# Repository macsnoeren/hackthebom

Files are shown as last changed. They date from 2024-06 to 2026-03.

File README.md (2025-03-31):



# Hack the Bom - Escape room challenge for cyber security

An escape room challenge type developed for the Avans University of Applied Sciences minor Cybersecurity: Resslient against cyber-crime.

Flash the latest version to your hardware: https://macsnoeren.github.io/hackthebom/

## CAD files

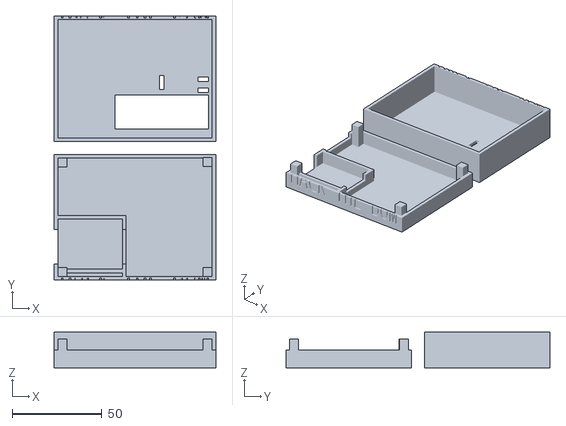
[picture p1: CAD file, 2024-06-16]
hardware/HackTheBox Casing.stl
90.0 x 147.0 x 20.0

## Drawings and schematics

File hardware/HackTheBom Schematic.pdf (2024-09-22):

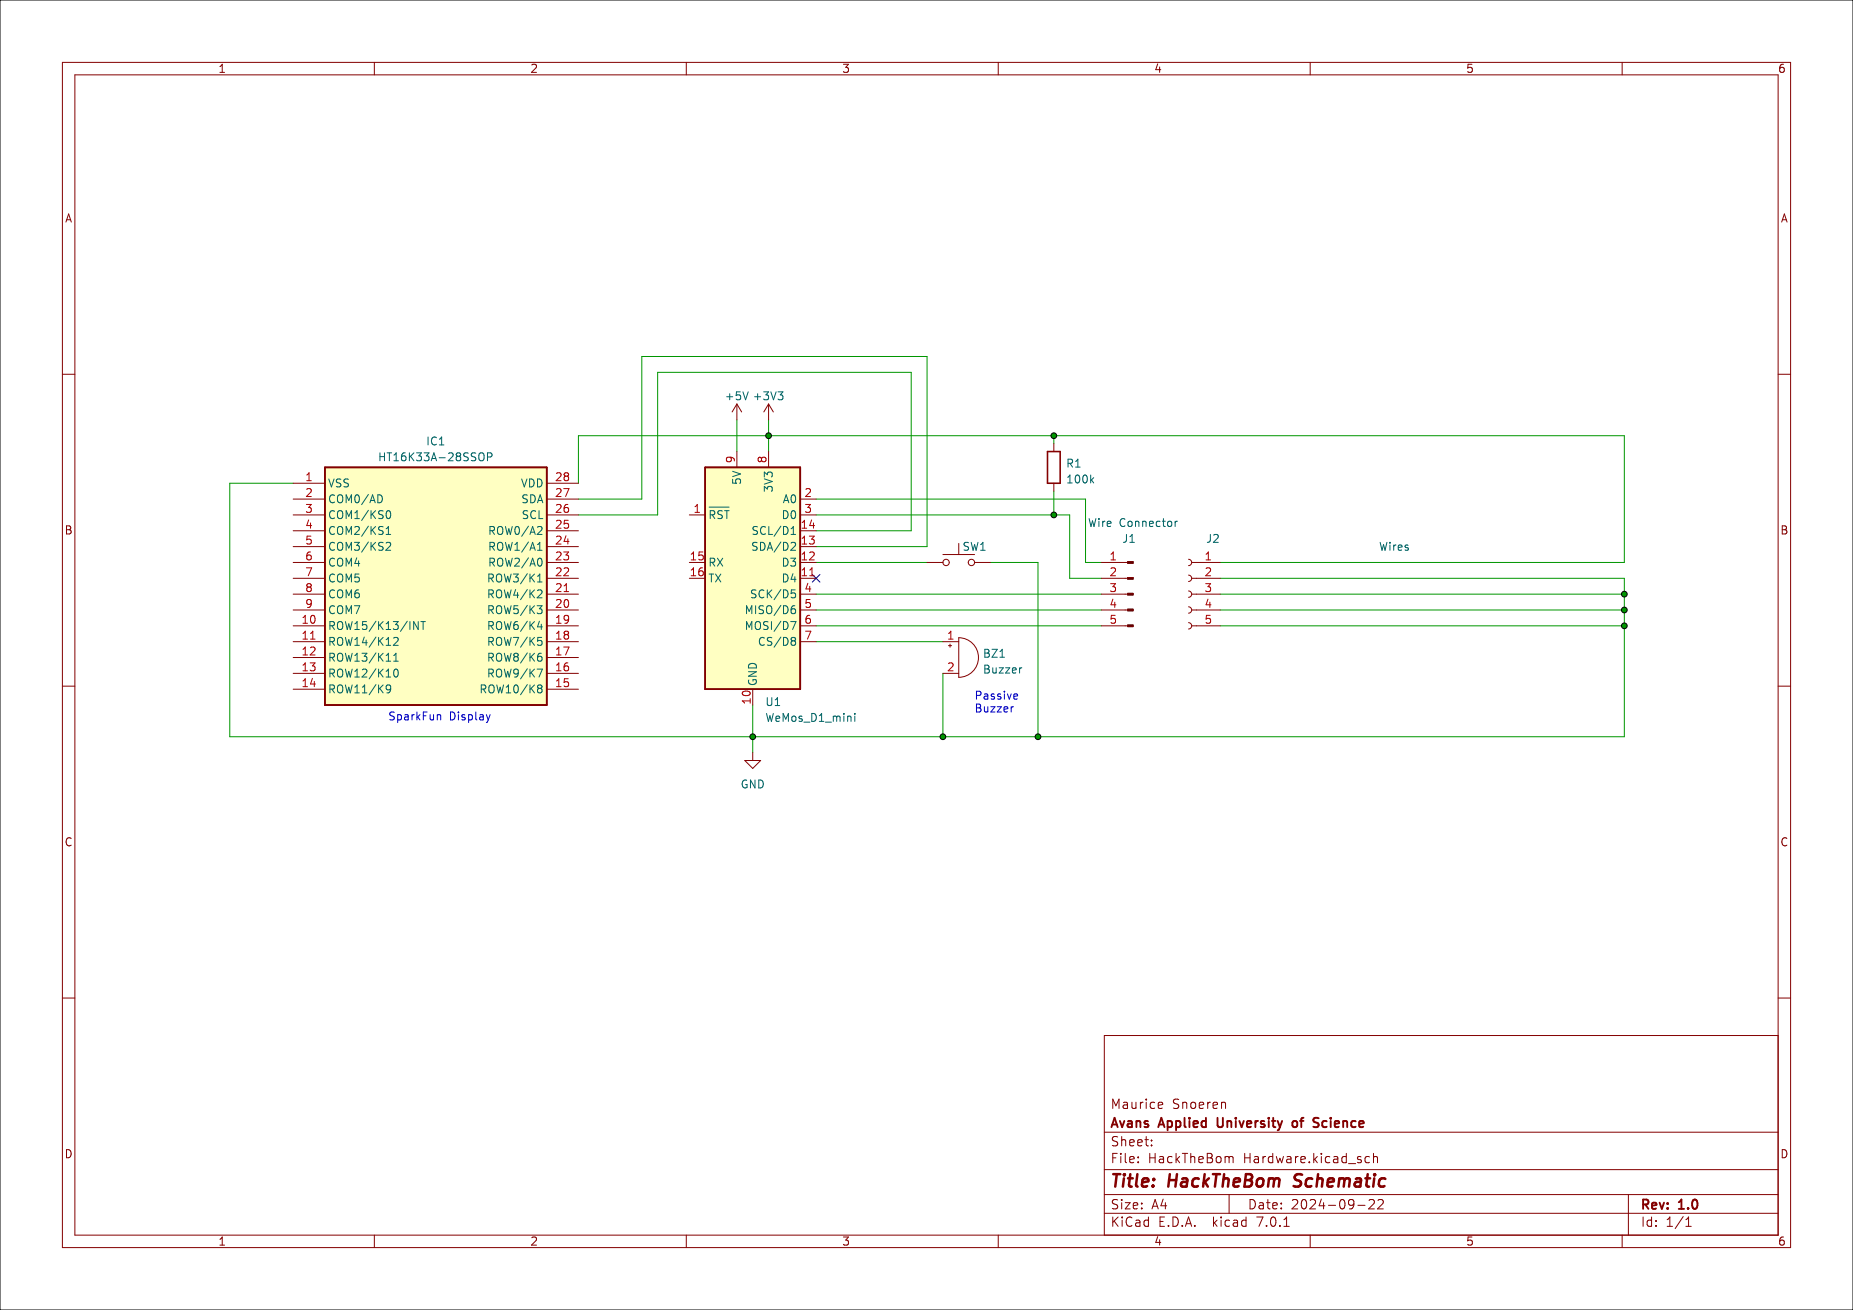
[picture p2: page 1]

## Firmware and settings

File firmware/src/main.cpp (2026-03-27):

/*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
 * @file       : main.cpp
 * @author     : Maurice Snoeren (MS)
 * @description: Main of the HackTheBom firmware application. HackTheBom is an
 *               escape room game that is used within Avans Hogeschool to teach
 *               students cyber security skills and knowledge. When the firmware
 *               starts, the teacher is able to select first the game that will
 *               be played. Enter the game is done using a long button press. 
 *               Then the time that the students get is selected and again with a
 *               long button press it is selected. To start the game the button
 *               is pressed again. The timer will start and the students need to
 *               solve the puzzle to defuse the (fake) bomb.
 *               The hardware:
 *               - Passive buzzer connected to D8 and GND.
 *               - 7-segment display connected to SCL (D1), SDA (D2), 5V and GND.
 *               - Button connected to D3.
 *               - 5 defuse wires connected to 1 (A0), 2 (D0), 3 (D5), 4 (D6), 5 (D7)
 *                 Wire connections: - A0 --- 3V3
 *                                   - D0 --- GND (external pull-up 100K to 3V3)
 *                                   - D5/D6/D7 --- GND (select internal pull-up)
 * @date       : 27-03-2026
 * @version    : 1.2
 * @updates    : 20-02-2024 (MS): Initial code.
 *               16-06-2024 (MS): Created the first release version.
 *               22-09-2024 (MS): Added Game 2 for the first year students including game selection.
 *               27-03-2026 (MS): Improved code and documentation.
 * @todo       : 
 */
#include <Arduino.h>
#include <math.h>
#include <ESP8266WiFi.h>
#include <ESP8266WebServer.h>
#include <EEPROM.h>
#include <driver.h>
#include <website.hpp>
#include <timer.hpp>
#include <buzzer.hpp>
#include <button.hpp>
#include <wires.hpp>

/// @brief Unieke SSID gebaseerd op de Chip ID.
String SSID = "HTB-" + String(system_get_chip_id());

/// @brief Wi-Fi wachtwoord (wordt geladen uit EEPROM of random gegenereerd).
String PASSWORD = "";

int channel = random(1, 13);
uint8_t GAME_SELECTION = 0;

// Forward declaration of the different routes for the webpages.
void handleRoot();
void handleAdmin();
void handleCode();
void handleNotFound();
String webDefusingCode = "";
uint8_t webDefusingCodeTrials = 0;

// Instantieer hardware drivers.
Timer timer;
Buzzer buzzer;
Button button;
Wires wires(&buzzer);
IDriver *drivers[] = { (IDriver*) &timer,
                       (IDriver*) &buzzer,
                       (IDriver*) &button,
                       (IDriver*) &wires,
                     };

ESP8266WebServer server(80);

/**
 * @enum MAIN_STATES
 * @brief De staten van de hoofd-state machine van het spel.
 */
enum MAIN_STATES {
  SELECT_GAME, ///< De leraar kiest het speltype.
  SELECT_TIME, ///< De leraar stelt de beschikbare tijd in.
  READY,       ///< Systeem is klaar voor de start (wacht op knopdruk).
  GAME_1,      ///< Game 1 (Draden) is actief.
  GAME_2,      ///< Game 2 (Web hacking) is actief.
  WIN,         ///< De bom is succesvol ontmanteld.
  LOSE,        ///< De bom is afgegaan.
  END,         ///< Einde van het spel, wacht op herstart.
};

// FSM state variable that indicate in which state we are in.
MAIN_STATES stateMain = SELECT_GAME;

// Total time that students get as default value in minutes (50 minutes).
uint8_t totalTimeDefault = 50;

/**
 * @brief Arduino Setup functie.
 * Initialiseert Seriële poort, EEPROM (voor wachtwoord), drivers en de webserver.
 */
void setup() {
  Serial.begin(115200);
  Serial.println("\nStarting HackTheBom Firmware...");

  /* Create a random number that will be used as Wi-Fi password. This number
   * will be stored in the EEPROM of the ESP8622.
   */ 
  EEPROM.begin(512);
  if ( EEPROM.read(0) != 0x55 ) { 
    // Geen wachtwoord gevonden, genereer een nieuwe van 20 cijfers.
    PASSWORD.reserve(20); 
    for ( uint8_t i=0; i < 20; i++ ) { // Create a random password
      uint8_t r = random(0, 10);
      PASSWORD += String(r);
      EEPROM.write(i+1, r); // Store it in the EEPROM
    }
    EEPROM.write(0, 0x55); // Everything is stored, so set the first byte to 0x55
    EEPROM.commit();

  } else {
    PASSWORD.reserve(20);
    for ( uint8_t i=0; i < 20; i++ ) {
      PASSWORD += String(EEPROM.read(i+1));
    }
  }

  // Start alle hardware drivers.
  for ( IDriver *driver: drivers ) {
      driver->setup();
  }

  // Print the name of the device and the password.
  printf("%s / %s\n", SSID.c_str(), PASSWORD.c_str());

  // Setup the Wi-Fi Access Point (AP)
  WiFi.softAP(SSID, PASSWORD, channel, 0, 1); // one client allowed!
  Serial.printf("AP IP address (channel %d): %s\n", channel, WiFi.softAPIP().toString().c_str());

  // Setup the routes to the webpages
  server.on("/", handleRoot);
  server.on("/admin", handleAdmin);
  server.on("/code", handleCode);
  server.onNotFound(handleNotFound);
  server.begin();

  // First state is blinking and show the default time.
  timer.blink(true);
  timer.showGameSelection(GAME_SELECTION+1);

  // Test the buzzer!
  buzzer.beep();

  // Setup is ready and print it to the serial.
  Serial.println("Ready.");
}

/**
 * @brief Arduino Loop functie.
 * Verwerkt driver updates en beheert de hoofd-state machine (FSM) zonder blocking code.
 */
void loop() {
  for ( IDriver *driver: drivers ) { // Call the loop functions of the drivers.
      driver->loop(millis());
  }
  
  // Implementation of the FSM by using a switch statement.
  switch (stateMain) {
    case SELECT_GAME:
      if ( button.isPressed() ) { // Wissel tussen Game 1 en Game 2
        GAME_SELECTION = (GAME_SELECTION+1) % 2;
        timer.showGameSelection(GAME_SELECTION+1);
        printf("GAME: %d\n", GAME_SELECTION);
      }

      if ( button.isLongPressed() ) { // Bevestig game keuze
        timer.showTime(totalTimeDefault, 0);
        stateMain = SELECT_TIME;
        buzzer.beep();
      }
    break;

    case SELECT_TIME:
      if ( button.isPressed() ) { // Verhoog tijd in stappen van 5 minuten
        totalTimeDefault = (totalTimeDefault + 5) % 100;
        timer.showTime(totalTimeDefault, 0);
      }

      if ( button.isLongPressed() ) { // Bevestig tijd
        timer.showTime(totalTimeDefault, 0);
        stateMain = READY;
        timer.blink(false);
        buzzer.beep();
      }
    break;

    case READY:
      if ( button.isPressed() ) { // START HET SPEL
        stateMain = GAME_1; // Default
        timer.enterCountdown(totalTimeDefault);
        buzzer.startTicking();
        wires.setup(); // Reset the game

        // Print the name of the device and the password.
        printf("%s / %s\n", SSID.c_str(), PASSWORD.c_str());
        printf("GAME: %d\n", GAME_SELECTION+1);

        if ( GAME_SELECTION == 0 ) { stateMain = GAME_1; }
        if ( GAME_SELECTION == 1 ) { 
          WiFi.softAP(SSID, "h4cKTh!5", channel, 0, 1); // Reset it to a fixed password for game 2 wi-fi
          stateMain = GAME_2;
        }
      }
    break;

    case GAME_1: // Draden spel (Minor Game)
     if ( wires.isWin() ) {
      stateMain = WIN;
      buzzer.startWin();
     }
    if ( timer.isTimerZero() || wires.isLose() ) { // Tijd op of te veel fouten
      stateMain = LOSE;
      buzzer.startLose();
     }
    break;

    case GAME_2: // Introduction, year 1 Game
    if ( webDefusingCode.equals("BC84") ) { // Hardcoded!
      stateMain = WIN;
      buzzer.startWin();
    }

    if ( timer.isTimerZero() || webDefusingCodeTrials > 3) {
      stateMain = LOSE;
      buzzer.startLose();
     }
    break;

    case WIN:
      timer.showYeah();
      stateMain = END;
    break;

    case LOSE:
      timer.showLose();
      stateMain = END;
    break;

    case END:
      static uint32_t end_timer = millis();
      if ( end_timer != 0 && millis() - end_timer > 20000 ) {
        buzzer.mute();
        end_timer = 0;
      }
      // Do nothing, so the device needs to be restarted.
    break;

    default:
      stateMain = SELECT_TIME;
  };

  // Call the loop function of the server to handle clients that are connected.
  server.handleClient();
}

/**
 * Handles the root webpage http://<ipaddress>/.
 *
 * @param None
 * @return None
 */
void handleRoot() {
  if ( GAME_SELECTION == 1 ) {
    server.send(200, "text/html", index_html_2);
    webDefusingCode = server.arg("code");
    if ( !webDefusingCode.equals("") ) {
      webDefusingCodeTrials++;
      if ( webDefusingCodeTrials > 0 ) {
        buzzer.startTicking(300); // double speed
      }
    }
    printf("webDefusingCode: %s\n", webDefusingCode.c_str());

  } else { // Default Game 1
    server.send(200, "text/html", index_html);
  }
}

/**
 * Handles the admin webpage http://<ipaddress>/admin.
 *
 * @param None
 * @return None
 */
void handleAdmin() {
  server.send(200, "text/html", admin_html);
}

/**
 * Handles the code webpage http://<ipaddress>/code.
 *
 * @param None
 * @return None
 */
void handleCode() {
  char html[1000];
  snprintf(html, sizeof(html), code_html, SSID.c_str(), wires.getCode());
  server.send(200, "text/html", html);
}

/**
 * Handles when a route does not exist.
 *
 * @param None
 * @return None
 */
void handleNotFound () {
  String message = "File Not Found\n\n";
  message += "URI: ";
  message += server.uri();
  message += "\nMethod: ";
  message += (server.method() == HTTP_GET)?"GET":"POST";
  message += "\nArguments: ";
  message += server.args();
  message += "\n";
  for (uint8_t i=0; i<server.args(); i++){
    message += " " + server.argName(i) + ": " + server.arg(i) + "\n";
  }
  server.send(404, "text/plain", message);
}

/* END OF FILE */

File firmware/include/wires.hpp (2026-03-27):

#pragma once
/**
 * This file is part of HackTheBom.
 * HackTheBom is free software: you can redistribute it and/or modify it under the
 * terms of the GNU General Public License as published by the Free Software 
 * Foundation, either version 3 of the License, or (at your option) any later 
 * version.
 * 
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
 * @file       : inclue/wires.cpp
 * @author     : Maurice Snoeren (MS)
 * @description: This file implements the driver for the defusing wires. 
 * @date       : 27-03-2026
 * @version    : 1.1
 * @updates    : 20-02-2024 (MS): Initial code.
 *               16-06-2024 (MS): Created the first release version.
 *               27-03-2026 (MS): Improved code and documentation.
 * @todo       : 
 */
#include <driver.h>

#include <Arduino.h>
#include <math.h>

#include <buzzer.hpp>

// Enumaration variable to define the order of the wires.
enum WIRE_NUMBER {
  WIRE_1,
  WIRE_2,
  WIRE_3,
  WIRE_4,
  WIRE_5
};

/**
 * @class Wires
 * @brief Beheert de status en ontmantelingslogica van de fysieke draden van de bom.
 * 
 * Deze klasse implementeert de IDriver interface en handelt het inlezen van de draden,
 * de softwarematige ontstoring (debounce) en de volgorde van doorknippen af.
 */
class Wires: public IDriver {
private:
  uint64_t timer;           ///< Timer voor non-blocking updates (anti-dender).
  uint8_t order[5];         ///< De juiste volgorde waarin draden doorgeknipt moeten worden.
  char code[5];             ///< Hexadecimale code gegenereerd uit de volgorde (verhoogd naar 5 voor null-terminator).
  uint8_t wires[5];         ///< Accumulator voor ontstoring per draad.
  uint8_t orderCut[5];      ///< Bijgehouden volgorde van doorgeknipte draden.
  uint8_t totalMistakes;    ///< Aantal fouten gemaakt door de gebruiker.
  uint8_t totalWireCuts;    ///< Totaal aantal draden dat momenteel is doorgeknipt.
  Buzzer* buzzer;           ///< Referentie naar de buzzer voor feedback.

  /**
   * @brief Controleert of een draadnummer al in de gegenereerde volgorde staat.
   * @param n Het draadnummer (1-5).
   * @return True als de draad al aanwezig is, anders false.
   */
  bool inWireOrder(uint8_t n) {
    for (uint8_t i=0; i < 5; i++ ) {
      if ( this->order[i] == n ) {
        return true;
      }
    }
    return false;
  }

  /**
   * @brief Print de gegenereerde draadvolgorde naar de seriële monitor voor debugging.
   */
  void printWireOrder () {
    printf("Wire order: \n");
    for (uint8_t i=0; i < 5; i++ ) {
      printf("%d\n", this->order[i]);
    }
    printf("\n");
  }

  /**
   * @brief Genereert een unieke hex-code gebaseerd op de ontmantelingsvolgorde.
   * De code wordt gebruikt in de web-interface.
   */
  void createCode () {
    uint32_t c = 0;
    for (uint8_t i=0; i < 5; i++ ) {
      c = c + (this->order[i] << (i*3));
    }
    // 15 bits max (5 * 3 bits) past in 4 hex karakters + \0. Buffer moet 5 groot zijn.
    snprintf(this->code, sizeof(this->code), "%X", c);
    printf("Code: %s\n", this->code);
  }

  /**
   * @brief Genereert een willekeurige volgorde voor de 5 draden.
   */
  void createRandomWireOrder() {
    //printf("Create random order\n");
    for (uint8_t i=0; i < 5; i++ ) {
      uint8_t n = (uint8_t) random(1, 6);
      while ( this->inWireOrder(n) ) {
        n = (uint8_t) random(1, 6);
      }
      //printf("Found number: %d\n", n);
      this->order[i] = n;
    }
    this->createCode();
  }

  /**
   * @brief Controleert of een specifieke draad al als "doorgeknipt" is geregistreerd.
   * @param n Draadnummer.
   * @return True als de draad al is doorgeknipt.
   */
  bool inWireOrderCut(uint8_t n) {
    for (uint8_t i=0; i < 5; i++ ) {
      if ( this->orderCut[i] == n ) {
        return true;
      }
    }
    return false;
  }

  /**
   * @brief Registreert een nieuwe draadknip en valideert of dit de juiste draad was.
   * Bij een foutieve draad wordt de ticking-snelheid van de buzzer verhoogd.
   * @param n Het nummer van de doorgeknipte draad.
   * @return True als de knip correct was volgens de volgorde.
   */
  bool addWireOrderCut(uint8_t n) {
    for (uint8_t i=0; i < 5; i++ ) {
      if ( this->orderCut[i] == 0 ) { // Found empty spot, put it in
        if ( this->order[i] == n ) { // correct wire
          printf("CORRECT WIRE\n");
          this->buzzer->beepCorrectWire();
          this->orderCut[i] = n;
          return true;

        } else { // not correct wire
          printf("NOT CORRECT WIRE\n");
          this->buzzer->beepNotCorrectWire();
          this->buzzer->startTicking(300); // double speed
          for (uint8_t i=0; i < 5; i++ ) {
            if ( this->order[i] == n ) { // find position of cut
              this->orderCut[i] = n; // put it on the correct position.
            }
          }
          return false;
        }
      }
    }
    return false;
  }
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

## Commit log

2024-06-10 Added button, buzzer, timer and wires driver.
    [main.cpp, wires.hpp]
2024-06-11 Finalized button with low-pass filter.
2024-06-12 Development progress added low-pass filter for the wires
2024-06-13 Wire logics and added home page
2024-06-15 fixed wire
2024-06-15 Experimenting with the buzzer
    [main.cpp, wires.hpp]
2024-06-16 Added the new timer version with documentation
2024-06-16 Finalized the code and the music and the logics for version 1
    [HTB Box.stl]
2024-06-16 Added documentation to driver.h about license
2024-06-22 Added parameter to set the speed of the ticker timer.
2024-06-22 Added double ticker timer if wrong wire is cut
    [wires.hpp]
2024-09-22 Added hardware documentation
    [HackTheBom Hardware.kicad_pcb, HackTheBom Hardware.kicad_sch, HackTheBox Casing.stl]
2024-10-01 Solved potential buffer overflow issue found by snyk
    [main.cpp]
2026-03-27 Fixed button problem and improved code structure and documentation.
    [main.cpp, wires.hpp]
2026-03-27 Added the correct versioning to the files
    [main.cpp, wires.hpp]
